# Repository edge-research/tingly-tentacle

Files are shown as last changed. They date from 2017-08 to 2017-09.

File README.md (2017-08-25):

# tingly-tentacle

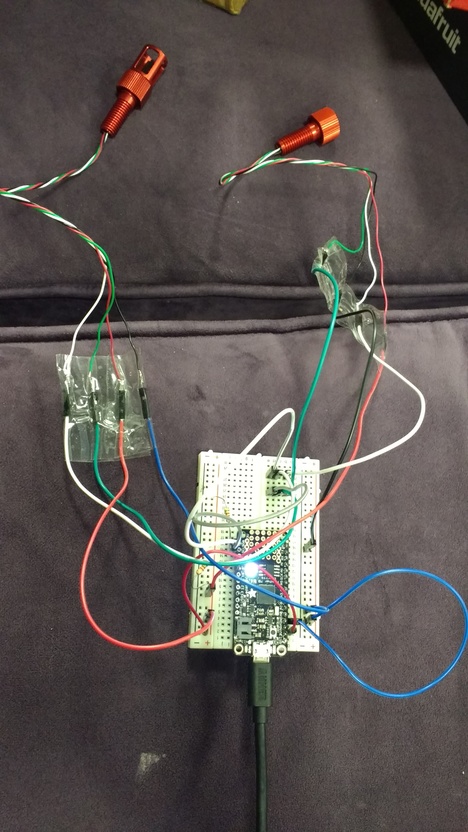
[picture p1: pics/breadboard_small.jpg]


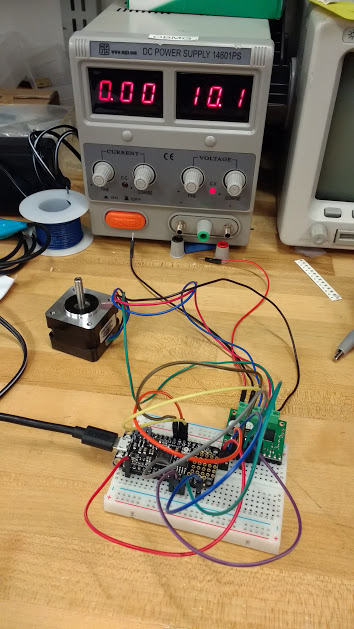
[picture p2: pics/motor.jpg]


# pololu stepper motor

- 1208 Stepper Motor: Bipolar, 200 Steps/Rev, 35×28mm, 10V, 0.5 A/Phase = 12.95
- https://www.pololu.com/product/1208

# pololu motor driver

- 2970 AMIS-30543 Stepper Motor Driver Carrier = 19.95
- https://www.pololu.com/product/2970
- http://www.onsemi.com/pub/Collateral/AMIS-30543-D.PDF
- https://github.com/pololu/amis-30543-arduino/

# blue robotics TSYS01

- https://github.com/bluerobotics/BlueRobotics_TSYS01_Library

# blue robotics MS5837

- http://docs.bluerobotics.com/bar30/
- https://github.com/bluerobotics/BlueRobotics_MS5837_Library

peristaltic pump system:
http://www.maschinenreich.com/wp-content/uploads/2017/03/XP88-Manual-A4-170320.pdf

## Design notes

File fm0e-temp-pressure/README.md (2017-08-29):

Datalogging temp and pressure (depth). 

# Adafruit Feather M0 Express

- [Adafruit Feather M0 Express Website](https://www.adafruit.com/product/3403) -- links and info.

# Blue Robotics TSYS01 'Fast Response' temp sensor

- [BR TSYS01 Website](https://www.bluerobotics.com/store/electronics/celsius-sensor-r1/) -- links and info.
- [BR TSYS01 Arduino Library](https://github.com/bluerobotics/BlueRobotics_TSYS01_Library)

# Blue Robotics MS5837 'Bar 30' pressure sensor

- [BR MS5837 Website](http://docs.bluerobotics.com/bar30/) -- links and info.
- [BR MS5837 Arduino Library](https://github.com/bluerobotics/BlueRobotics_MS5837_Library)

# Setup

- We're going to be programming the device using the Arduino IDE, but fetching the data off using CircuitPython. This allows us to utilize the on-board SPI Flash chip, which is lower-power and (likely) more reliable than an SD card.

- The Blue Robotics sensors should be connected to the Feather via i2c lines.  Follow the wiring diagrams on their respective web pages.  The SDA and SCL lines will each need a 10K 'pullup' -- i.e. they each need to be connected via a 10K resistor to VCC (3.3 V).

- Install the above Arduino libraries for the temp sensor and the pressure sensor in the 'libraries' folder for your Arduino installation.

- Set up your Arduino IDE to allow for interacting with Feather M0 Express boards as per instructions here.

### Initial programming of board for datalogging

- Double tap the 'reset' button to enter bootloader mode.
 
- Upload the 'feather_m0_express_br_temp_br_pressure_logger.ino' in this repo to the board.

- Once uploaded, double tap the 'reset' button again to enter bootloader mode.  Copy the '.UF2' file off the 'FEATHERBOOT' drive and store it.  This is your 'datalogger program', and will be needed after each time you collect data.
 
### Collecting the data after datalogging

- Double tap the 'reset' button to enter bootloader mode.

- Drag and drop the 'adafruit-circuitpython-feather_m0_express-2.0.0-beta.1.uf2' file onto the FEATHEROOT drive. 

- This will automatically reboot the board, and then mount as a 'CIRCUITPYTHON' drive. You can then drag-drop off the 'data.txt' file.

### Reprogramming the board to return to datalogging

- Double tap the 'reset' button to enter bootloader mode.

- Drag and drop your '.UF2' file (saved in step 1.) back onto the FEATHERBOOT drive.  This will automatically reboot the system and start running the Arduino datalogging program (may require a power cycle).

# Misc Notes

These sensors use 'D13' connectors for the i2c connection. Looks like matching connectors are avail on Digikey [here](https://www.digikey.com/product-detail/en/hirose-electric-co-ltd/DF13-4P-1.25DSA/H2193-ND/241767).

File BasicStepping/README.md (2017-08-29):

Uses the [AMIS-30543 Arduino library](https://github.com/edge-research/tingly-tentacle/tree/master/BasicStepping).  Code and wiring instructions [here](https://github.com/pololu/amis-30543-arduino).

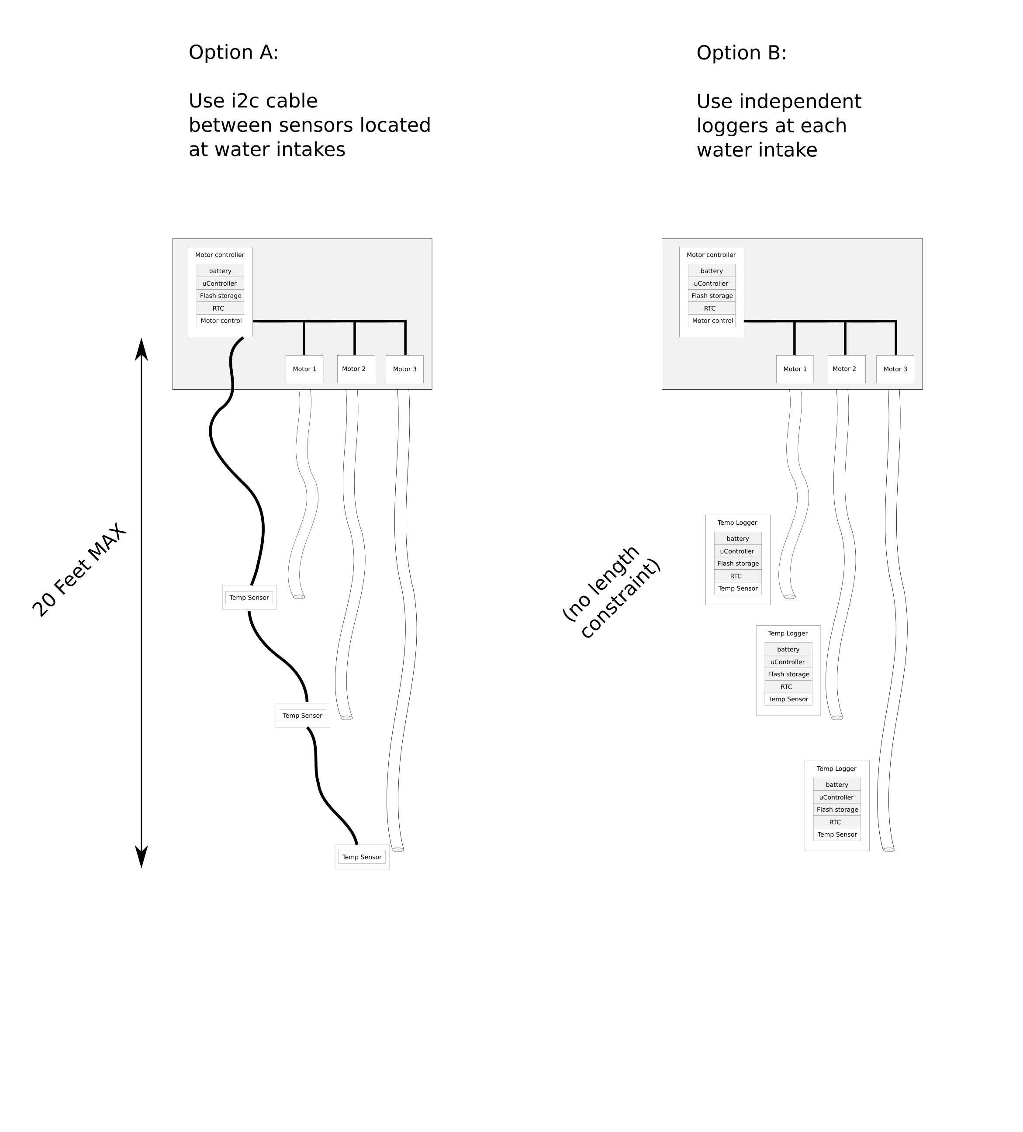
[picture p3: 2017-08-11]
docs/tt1.png

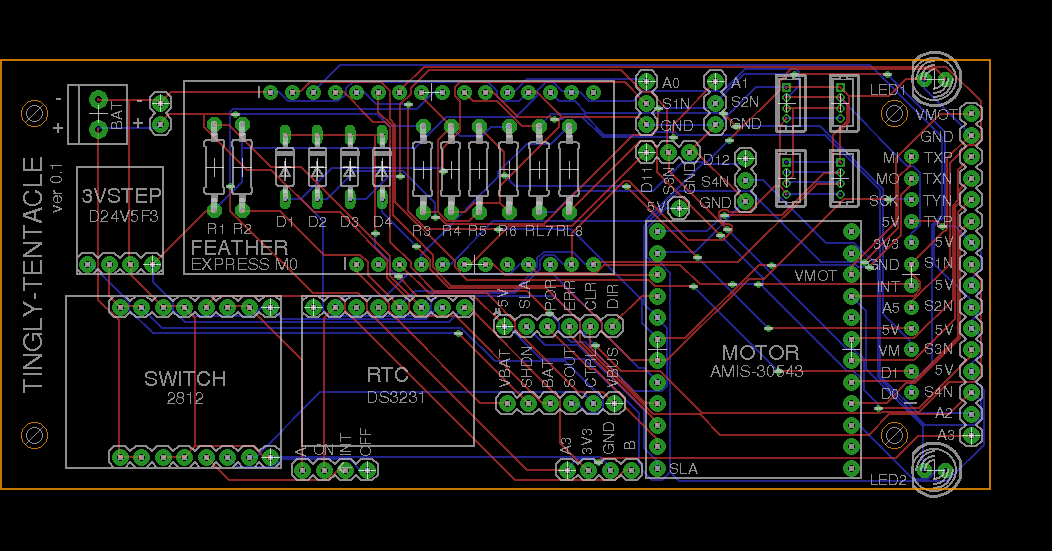
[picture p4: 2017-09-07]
mother_board/mother3.png

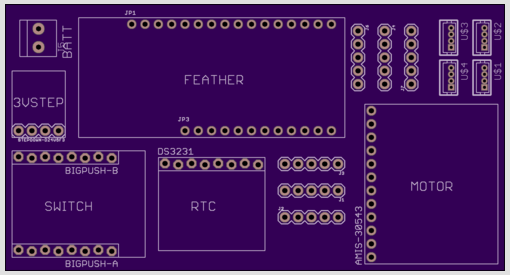
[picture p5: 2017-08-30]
mother_board/tingle-top.png

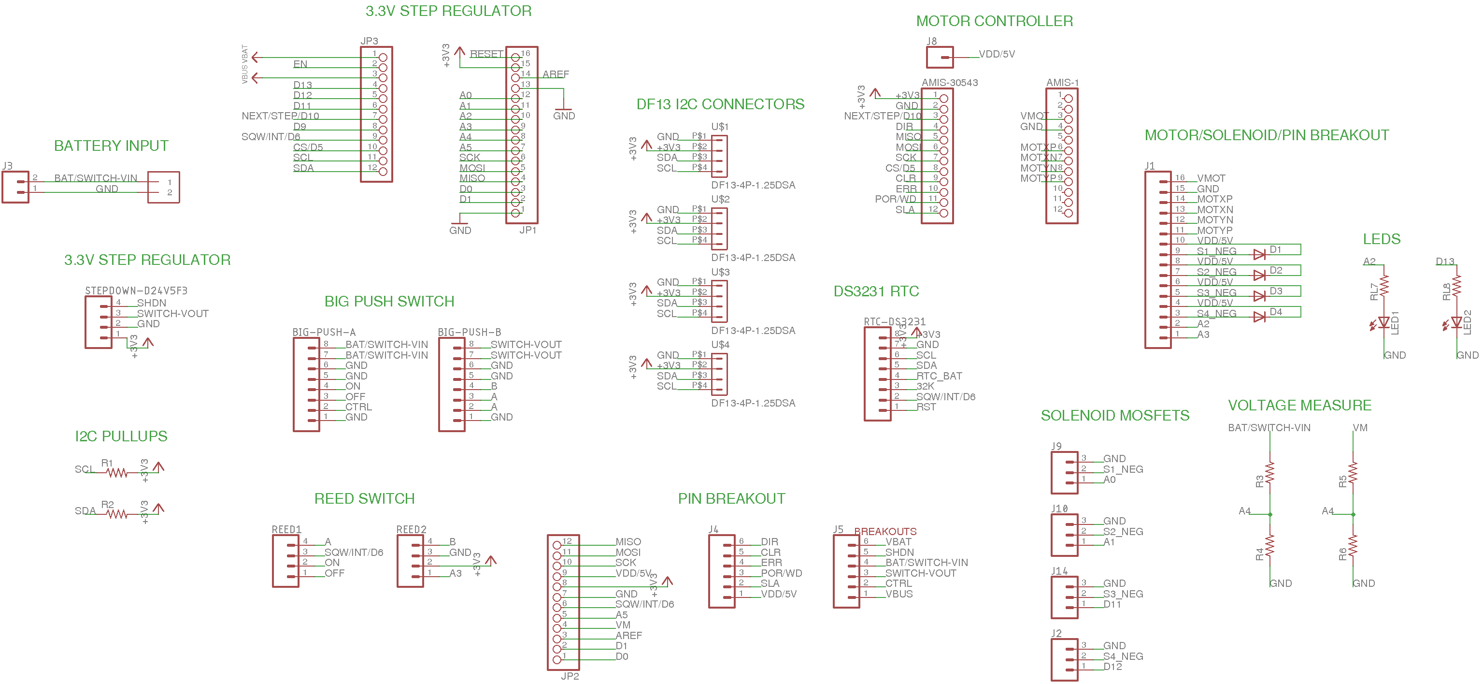
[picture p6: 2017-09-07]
mother_board/mother3_schem.png

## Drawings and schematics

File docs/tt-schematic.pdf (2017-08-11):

# Option A:

# Use i2c cable

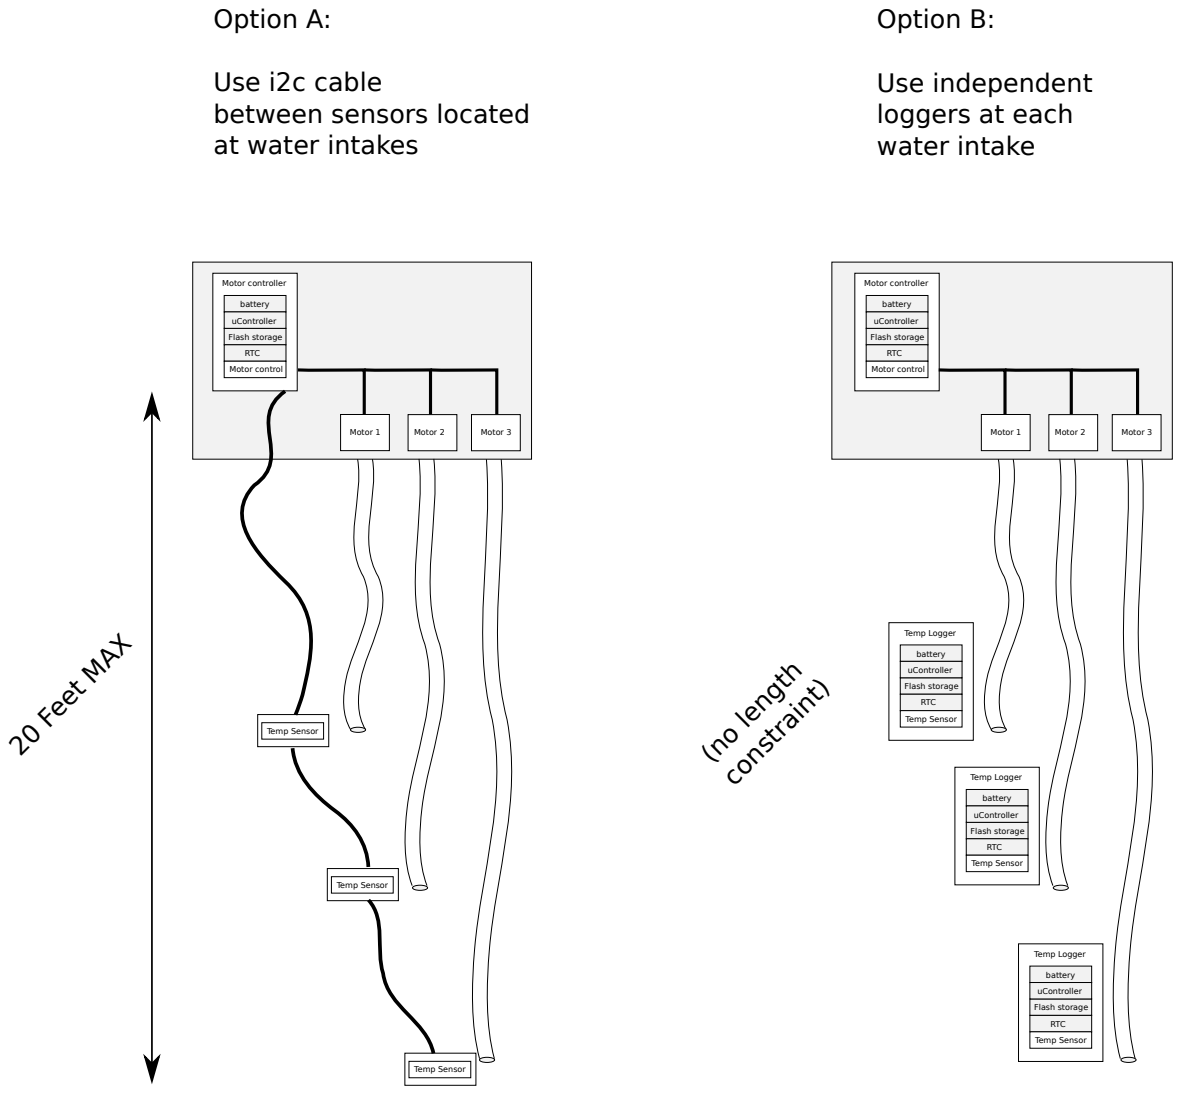
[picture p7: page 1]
RTC; battery; Flash storage; uController; Motor controller; Motor control; Motor 1; Motor 2; Motor 3; Temp Logger; Temp Sensor; 20 Feet MAX; (no length constraint); Option B:

Use independent
loggers at each
water intake

between sensors located
at water intakes

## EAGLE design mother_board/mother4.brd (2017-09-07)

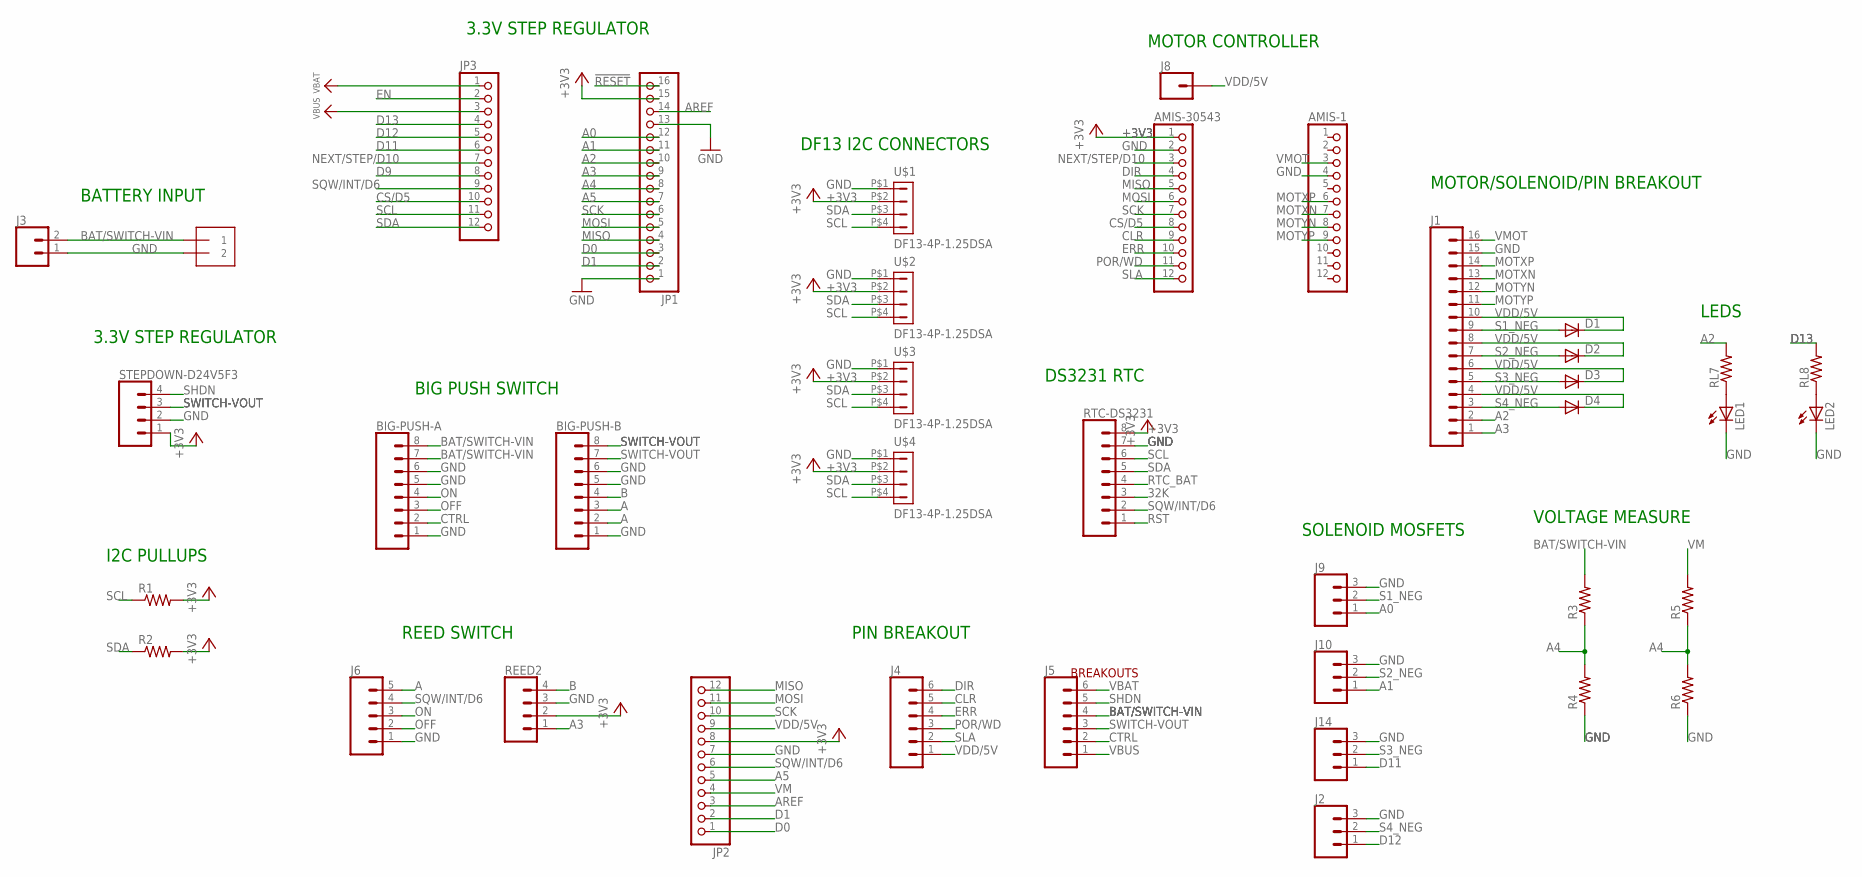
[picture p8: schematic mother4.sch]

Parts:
AMIS-1, AMIS-30543: PINHD-1X12-CB; 1X12-CB
BAT: 1X2-3.5MM
BIG-PUSH-A: CONN_08"; 1X08
BIG-PUSH-B: CONN_08"; 1X08
D1, D2, D3, D4: 1N4148DO35-7; DO35-7
J1: CONN_16; 1X16
J2, J9, J10, J14: CONN_03; 1X03
J3: CONN_02; 1X02
J4, J5: CONN_06SILK_FEMALE_PTH; 1X06
J6: CONN_05; 1X05
J8: CONN_01; 1X01
JP1: HEADER-1X16ROUND; 1X16_ROUND
JP2, JP3: HEADER-1X12; 1X12_ROUND
LED1, LED2: LED5MM
R1, R2, R3, R4, R5, R6: R-US_0207/10; 0207/10
REED2: CONN_04; 1X04
RL7, RL8: R-US_0207/10; 0207/10
RTC-DS3231: CONN_08"; 1X08
STEPDOWN-D24V5F3: CONN_04; 1X04
U$1, U$2, U$3, U$4: DF13-4P-1.25DSA

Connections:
32K: RTC-DS3231.3
!RESET: JP1.16
+3V3: AMIS-30543.1, JP1.15, JP2.8, R1.2, R2.2, REED2.2, RTC-DS3231.8, STEPDOWN-D24V5F3.1, U$1.P$2 (2), U$2.P$2 (2), U$3.P$2 (2), U$4.P$2 (2)
A: BIG-PUSH-B.2, BIG-PUSH-B.3, J6.5
A0: J9.1, JP1.12
A1: J10.1, JP1.11
A2: J1.2, JP1.10, RL7.2
A3: J1.1, JP1.9, REED2.1
A4: JP1.8, R3.1, R4.2, R5.1, R6.2
A5: JP1.7, JP2.5
AREF: JP1.14, JP2.3
B: BIG-PUSH-B.4, REED2.4
BAT/SWITCH-VIN: BAT.1, BIG-PUSH-A.7, BIG-PUSH-A.8, J3.2, J5.4, R3.2
CLR: AMIS-30543.9, J4.5
CS/D5: AMIS-30543.8, JP3.10
CTRL: BIG-PUSH-A.2, J5.2
D0: JP1.3, JP2.1
D1: JP1.2, JP2.2
D9: JP3.8
D11: J14.1, JP3.6
D12: J2.1, JP3.5
D13: JP3.4, RL8.2
DIR: AMIS-30543.4, J4.6
EN: JP3.2
ERR: AMIS-30543.10, J4.4
GND: AMIS-1.4, AMIS-30543.2, BAT.2, BIG-PUSH-A.1, BIG-PUSH-A.5, BIG-PUSH-A.6, BIG-PUSH-B.1, BIG-PUSH-B.5, BIG-PUSH-B.6, J1.15, J2.3, J3.1, J6.1, J9.3, J10.3, J14.3, JP1.1, JP1.13, JP2.7, LED1.K (C), LED2.K (C), R4.1, R6.1, REED2.3, RTC-DS3231.7, STEPDOWN-D24V5F3.2, U$1.P$1 (1), U$2.P$1 (1), U$3.P$1 (1), U$4.P$1 (1)
MISO: AMIS-30543.5, JP1.4, JP2.12
MOSI: AMIS-30543.6, JP1.5, JP2.11
MOTXN: AMIS-1.7, J1.13
MOTXP: AMIS-1.6, J1.14
MOTYN: AMIS-1.8, J1.12
MOTYP: AMIS-1.9, J1.11
unnamed: LED1.A, RL7.1
unnamed: LED2.A, RL8.1
NEXT/STEP/D10: AMIS-30543.3, JP3.7
OFF: BIG-PUSH-A.3, J6.2
ON: BIG-PUSH-A.4, J6.3
POR/WD: AMIS-30543.11, J4.3
RST: RTC-DS3231.1
RTC_BAT: RTC-DS3231.4
S1_NEG: D1.A, J1.9, J9.2
S2_NEG: D2.A, J1.7, J10.2
S3_NEG: D3.A, J1.5, J14.2
S4_NEG: D4.A, J1.3, J2.2
SCK: AMIS-30543.7, JP1.6, JP2.10
SCL: JP3.11, R1.1, RTC-DS3231.6, U$1.P$4 (4), U$2.P$4 (4), U$3.P$4 (4), U$4.P$4 (4)
SDA: JP3.12, R2.1, RTC-DS3231.5, U$1.P$3 (3), U$2.P$3 (3), U$3.P$3 (3), U$4.P$3 (3)
SHDN: J5.5, STEPDOWN-D24V5F3.4
SLA: AMIS-30543.12, J4.2
SQW/INT/D6: J6.4, JP2.6, JP3.9, RTC-DS3231.2
SWITCH-VOUT: BIG-PUSH-B.7, BIG-PUSH-B.8, J5.3, STEPDOWN-D24V5F3.3
VBAT: J5.6, JP3.1
VBUS: J5.1, JP3.3
VDD/5V: D1.C, D2.C, D3.C, D4.C, J1.4, J1.6, J1.8, J1.10, J4.1, J8.1, JP2.9
VM: JP2.4, R5.2
VMOT: AMIS-1.3, J1.16

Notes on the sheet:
BREAKOUTS
BATTERY INPUT
3.3V STEP REGULATOR
BIG PUSH SWITCH
REED SWITCH
PIN BREAKOUT
DS3231 RTC
SOLENOID MOSFETS
MOTOR/SOLENOID/PIN BREAKOUT
MOTOR CONTROLLER
I2C PULLUPS
DF13 I2C CONNECTORS
VOLTAGE MEASURE
LEDS

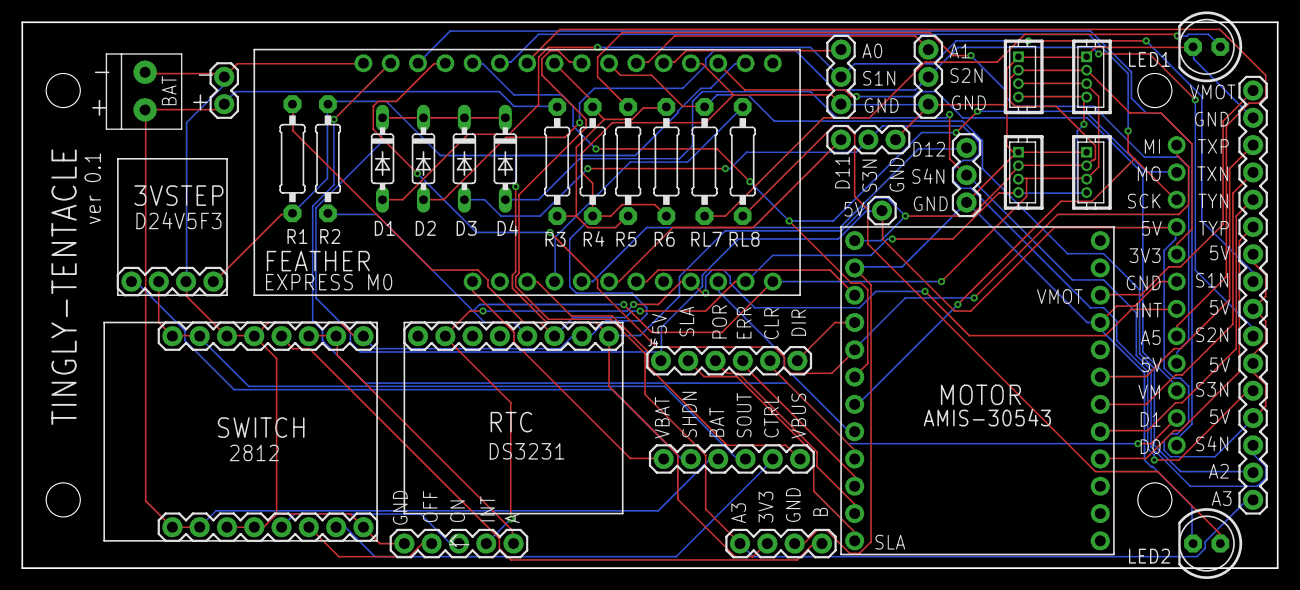
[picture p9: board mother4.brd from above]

Board: 2 copper layers, 116.8 x 50.8 mm, 39 parts (0 on the bottom side), 50 nets.

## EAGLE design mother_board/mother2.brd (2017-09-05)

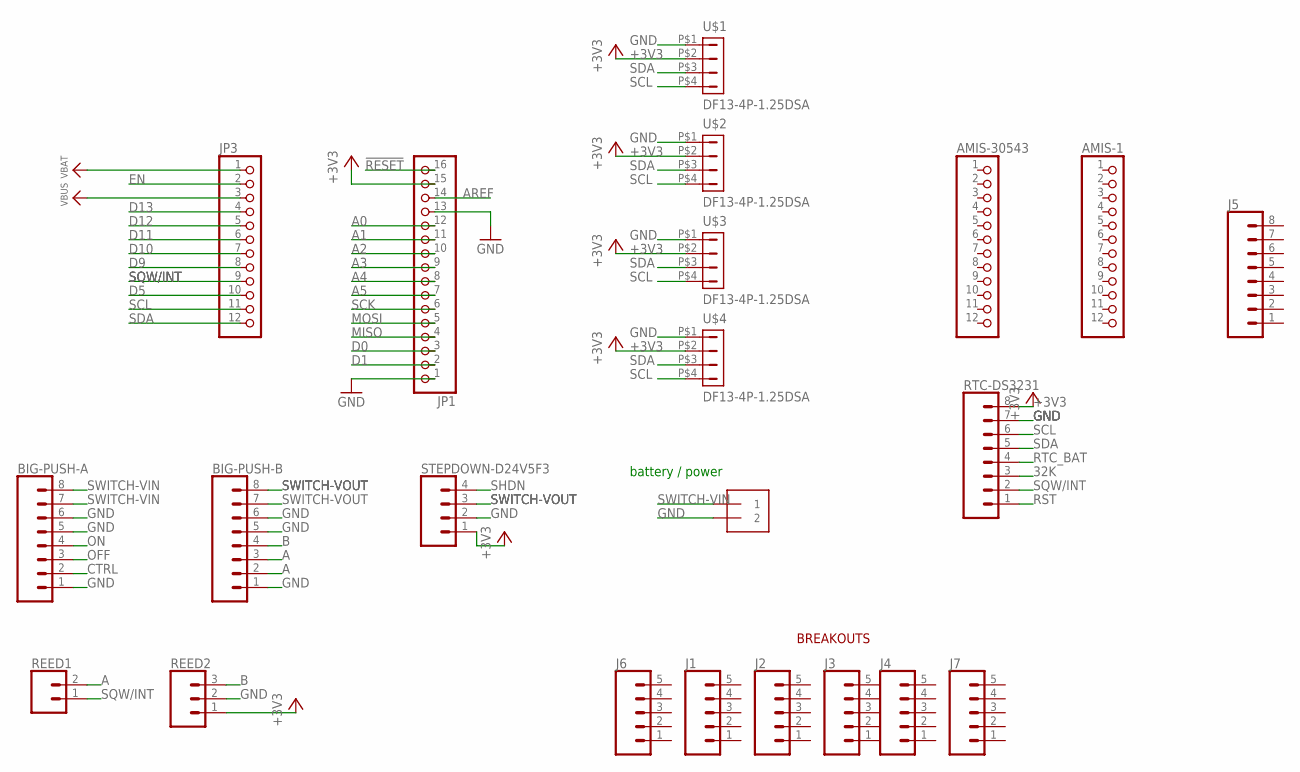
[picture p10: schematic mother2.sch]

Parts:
AMIS-1, AMIS-30543: PINHD-1X12-CB; 1X12-CB
BAT: 1X2-3.5MM
BIG-PUSH-A: CONN_08"; 1X08
BIG-PUSH-B: CONN_08"; 1X08
J1, J2, J3, J4, J6, J7: CONN_05; 1X05
J5: CONN_08"; 1X08
JP1: HEADER-1X16ROUND; 1X16_ROUND
JP3: HEADER-1X12; 1X12_ROUND
REED1: CONN_02; 1X02
REED2: CONN_03; 1X03
RTC-DS3231: CONN_08"; 1X08
STEPDOWN-D24V5F3: CONN_04; 1X04
U$1, U$2, U$3, U$4: DF13-4P-1.25DSA

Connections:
32K: RTC-DS3231.3
!RESET: JP1.16
+3V3: JP1.15, REED2.1, RTC-DS3231.8, STEPDOWN-D24V5F3.1, U$1.P$2 (2), U$2.P$2 (2), U$3.P$2 (2), U$4.P$2 (2)
A: BIG-PUSH-B.2, BIG-PUSH-B.3, REED1.2
A0: JP1.12
A1: JP1.11
A2: JP1.10
A3: JP1.9
A4: JP1.8
A5: JP1.7
AREF: JP1.14
B: BIG-PUSH-B.4, REED2.3
CTRL: BIG-PUSH-A.2
D0: JP1.3
D1: JP1.2
D5: JP3.10
D9: JP3.8
D10: JP3.7
D11: JP3.6
D12: JP3.5
D13: JP3.4
EN: JP3.2
GND: BAT.2, BIG-PUSH-A.1, BIG-PUSH-A.5, BIG-PUSH-A.6, BIG-PUSH-B.1, BIG-PUSH-B.5, BIG-PUSH-B.6, JP1.1, JP1.13, REED2.2, RTC-DS3231.7, STEPDOWN-D24V5F3.2, U$1.P$1 (1), U$2.P$1 (1), U$3.P$1 (1), U$4.P$1 (1)
MISO: JP1.4
MOSI: JP1.5
OFF: BIG-PUSH-A.3
ON: BIG-PUSH-A.4
RST: RTC-DS3231.1
RTC_BAT: RTC-DS3231.4
SCK: JP1.6
SCL: JP3.11, RTC-DS3231.6, U$1.P$4 (4), U$2.P$4 (4), U$3.P$4 (4), U$4.P$4 (4)
SDA: JP3.12, RTC-DS3231.5, U$1.P$3 (3), U$2.P$3 (3), U$3.P$3 (3), U$4.P$3 (3)
SHDN: STEPDOWN-D24V5F3.4
SQW/INT: JP3.9, REED1.1, RTC-DS3231.2
SWITCH-VIN: BAT.1, BIG-PUSH-A.7, BIG-PUSH-A.8
SWITCH-VOUT: BIG-PUSH-B.7, BIG-PUSH-B.8, STEPDOWN-D24V5F3.3
VBAT: JP3.1
VBUS: JP3.3

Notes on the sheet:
BREAKOUTS
battery / power

Board: 2 copper layers, 22 parts (0 on the bottom side), 9 nets, no tracks yet.

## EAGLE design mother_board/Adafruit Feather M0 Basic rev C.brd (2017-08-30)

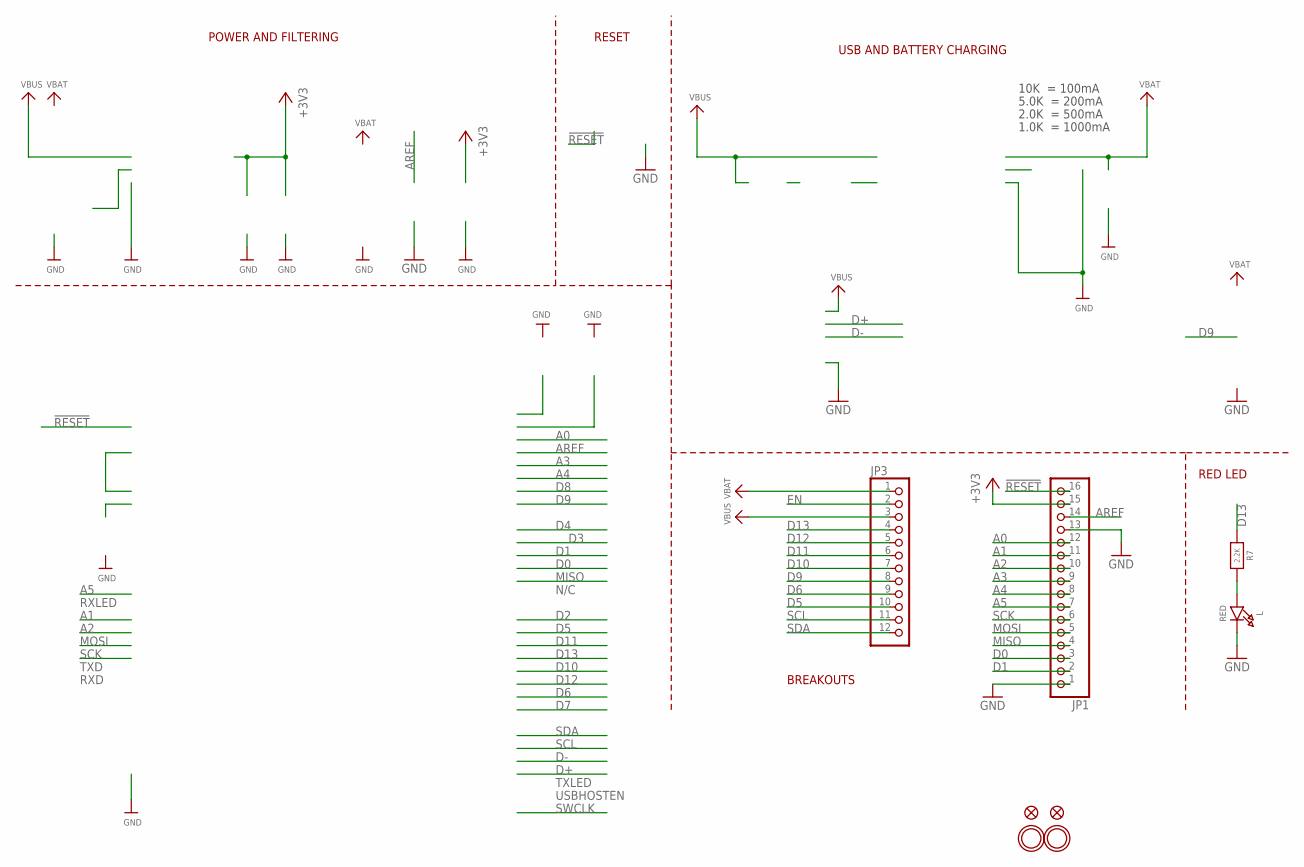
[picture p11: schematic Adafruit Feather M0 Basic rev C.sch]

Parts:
JP1: HEADER-1X16ROUND; 1X16_ROUND
JP3: HEADER-1X12; 1X12_ROUND
L: RED; CHIPLED_0805_NOOUTLINE
R7: 2.2K; 0603-NO
U$31, U$32: MOUNTINGHOLE2.5; MOUNTINGHOLE_2.5_PLATED
U$34, U$35: FIDUCIAL""; FIDUCIAL_1MM

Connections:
!RESET: JP1.16
+3V3: JP1.15
A0: JP1.12
A1: JP1.11
A2: JP1.10
A3: JP1.9
A4: JP1.8
A5: JP1.7
AREF: JP1.14
D0: JP1.3
D1: JP1.2
D5: JP3.10
D6: JP3.9
D9: JP3.8
D10: JP3.7
D11: JP3.6
D12: JP3.5
D13: JP3.4, R7.1
EN: JP3.2
GND: JP1.1, JP1.13, L.C
MISO: JP1.4
MOSI: JP1.5
unnamed: L.A, R7.2
SCK: JP1.6
SCL: JP3.11
SDA: JP3.12
VBAT: JP3.1
VBUS: JP3.3

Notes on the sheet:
POWER AND FILTERING
RESET
10K = 100mA
5.0K = 200mA
2.0K = 500mA
1.0K = 1000mA
N/C
TXLED
USBHOSTEN
RXLED
TXD
RXD
USB AND BATTERY CHARGING
BREAKOUTS
RED LED

Board: 2 copper layers, 12 parts (3 on the bottom side), 3 nets, no tracks yet.

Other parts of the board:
U$7, U$12: ADAFRUIT_3.5MM
U$9: FEATHERLOGO
U$13: PCBFEAT-REV-040

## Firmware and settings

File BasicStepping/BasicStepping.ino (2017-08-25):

/* This example shows basic use of the AMIS-30543 stepper motor
driver.

It shows how to initialize the driver, set the current limit, set
the micro-stepping mode, and enable the driver.  It shows how to
send pulses to the NXT/STEP pin to get the driver to take steps
and how to switch directions using the DIR pin.  The DO pin is
not used and does not need to be connected.

Before using this example, be sure to change the
setCurrentMilliamps line to have an appropriate current limit for
your system.  Also, see this library's documentation for
information about how to connect the driver:

    http://pololu.github.io/amis-30543-arduino/
*/

#include <SPI.h>
#include <AMIS30543.h>

const uint8_t amisDirPin = 12;
const uint8_t amisStepPin = 11;
const uint8_t amisSlaveSelect = 10;

AMIS30543 stepper;

void setup()
{

  pinMode(LED_BUILTIN, OUTPUT);


for (int i=0; i<5;i++) {
  digitalWrite(LED_BUILTIN, HIGH);   // turn the LED on (HIGH is the voltage level)
  delay(1000);                       // wait for a second
  digitalWrite(LED_BUILTIN, LOW);    // turn the LED off by making the voltage LOW
  delay(1000);  

}
  
  SPI.begin();
  stepper.init(amisSlaveSelect);

  // Drive the NXT/STEP and DIR pins low initially.
  digitalWrite(amisStepPin, LOW);
  pinMode(amisStepPin, OUTPUT);
  digitalWrite(amisDirPin, LOW);
  pinMode(amisDirPin, OUTPUT);

  // Give the driver some time to power up.
  delay(1);

  // Reset the driver to its default settings.
  stepper.resetSettings();

  // Set the current limit.  You should change the number here to
  // an appropriate value for your particular system.
  stepper.setCurrentMilliamps(132);

  // Set the number of microsteps that correspond to one full step.
  stepper.setStepMode(32);

  // Enable the motor outputs.
  stepper.enableDriver();

  digitalWrite(LED_BUILTIN, HIGH);   // turn the LED on (HIGH is the voltage level)
  delay(200);                       // wait for a second
  digitalWrite(LED_BUILTIN, LOW);    // turn the LED off by making the voltage LOW
  delay(200);  
  
}

void loop()
{

  digitalWrite(LED_BUILTIN, HIGH);   // turn the LED on (HIGH is the voltage level)
  delay(1000);                       // wait for a second
  digitalWrite(LED_BUILTIN, LOW);    // turn the LED off by making the voltage LOW
  delay(1000);  
  
  // Step in the default direction 1000 times.
  setDirection(0);
  for (unsigned int x = 0; x < 1000; x++)
  {
    step();
  }

  // Wait for 300 ms.
  delay(300);

  // Step in the other direction 1000 times.
  setDirection(1);
  for (unsigned int x = 0; x < 1000; x++)
  {
    step();
  }

  // Wait for 300 ms.
  delay(300);
}

// Sends a pulse on the NXT/STEP pin to tell the driver to take
// one step, and also delays to control the speed of the motor.
void step()
{
  // The NXT/STEP minimum high pulse width is 2 microseconds.
  digitalWrite(amisStepPin, HIGH);
  delayMicroseconds(3);
  digitalWrite(amisStepPin, LOW);
  delayMicroseconds(3);

  // The delay here controls the stepper motor's speed.  You can
  // increase the delay to make the stepper motor go slower.  If
  // you decrease the delay, the stepper motor will go fast, but
  // there is a limit to how fast it can go before it starts
  // missing steps.
  delayMicroseconds(2000);
}

// Writes a high or low value to the direction pin to specify
// what direction to turn the motor.
void setDirection(bool dir)
{
  // The NXT/STEP pin must not change for at least 0.5
  // microseconds before and after changing the DIR pin.
  delayMicroseconds(1);
  digitalWrite(amisDirPin, dir);
  delayMicroseconds(1);
}

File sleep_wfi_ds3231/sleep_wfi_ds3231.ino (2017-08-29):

//Interrupts for Battery management/saving using MCU power down mode. /INT from DS3231 is connected to 'interrupt_pin' of MCU, and also needs a 10K pullup to VDD.

#include <Wire.h>
#include "DS3231.h"

#define interruptPin 6

DS3231 rtc; //Create the DS3231 object

const int interval_sec = 5; //interval in seconds
const int sleep_depth = 0; // Enable Idle0 mode - sleep CPU clock only
//const int sleep_depth = 1; // Idle1 - sleep CPU and AHB clocks
//const int sleep_depth=2; // Idle2 - sleep CPU, AHB, and APB clocks

void setup () 
{

  
	 Serial.begin(9600);
   Serial.println('beginning ...');
	 Wire.begin();
	
	 rtc.begin(); 
   
}


void loop () 
{

	for (int i=0;i<3;i++) { // indicate visually
    Blink(LED_BUILTIN,1000);
   }
   
   fall_asleep(interval_sec,sleep_depth);

   for (int i=0;i<3;i++) { // indicate visually
    Blink(LED_BUILTIN,100);
   }
   delay(1000);
   Serial.println(" External Interrupt detected "); //indicate on serial port

} 

  
//Interrupt service routine for external interrupt
void EIC_ISR()
{
  //Keep this as short as possible. Possibly avoid using function calls
  detachInterrupt(digitalPinToInterrupt(interruptPin));
  
}

void Blink(byte PIN, int DELAY_MS) {
  //Blink an LED
  pinMode(PIN, OUTPUT);
  digitalWrite(PIN, HIGH);
  delay(DELAY_MS);
  digitalWrite(PIN, LOW);
  delay(DELAY_MS);
}


void fall_asleep (int interval_sec, int sleep_depth) {

  rtc.clearAlarm(); //resets the alarm interrupt status on the RTC
  attachInterrupt(digitalPinToInterrupt(interruptPin), EIC_ISR, FALLING);  // Attach interrupt to pin interrupt_pin with an ISR
 
  SYSCTRL->XOSC32K.reg |=  (SYSCTRL_XOSC32K_RUNSTDBY | SYSCTRL_XOSC32K_ONDEMAND); // set external 32k oscillator to run when idle or sleep mode is chosen
  REG_GCLK_CLKCTRL  |= GCLK_CLKCTRL_ID(GCM_EIC) |  // generic clock multiplexer id for the external interrupt controller
                       GCLK_CLKCTRL_GEN_GCLK1 |  // generic clock 1 which is xosc32k
                       GCLK_CLKCTRL_CLKEN;       // enable it
  while (GCLK->STATUS.bit.SYNCBUSY);              // write protected, wait for sync

  EIC->WAKEUP.reg |= EIC_WAKEUP_WAKEUPEN4;        // Set External Interrupt Controller to use channel 4 (interrupt_pin)


  if (sleep_depth==0) PM->SLEEP.reg |= PM_SLEEP_IDLE_CPU;  // Enable Idle0 mode - sleep CPU clock only
  if (sleep_depth==1) PM->SLEEP.reg |= PM_SLEEP_IDLE_AHB; // Idle1 - sleep CPU and AHB clocks
  if (sleep_depth==2) PM->SLEEP.reg |= PM_SLEEP_IDLE_APB; // Idle2 - sleep CPU, AHB, and APB clocks

  // It is either Idle mode or Standby mode, not both. 
  SCB->SCR |= SCB_SCR_SLEEPDEEP_Msk;   // Enable Standby or "deep sleep" mode
  
  
  DateTime now = rtc.now(); //get the current time
  DateTime nextAlarm = DateTime(now.unixtime() + interval_sec);
  rtc.enableAlarm(nextAlarm); //Sets the alarm on the RTC to the specified time (using the DateTime Object passed in)
  delay(10); //wait for a moment for everything to complete
  __WFI();
}

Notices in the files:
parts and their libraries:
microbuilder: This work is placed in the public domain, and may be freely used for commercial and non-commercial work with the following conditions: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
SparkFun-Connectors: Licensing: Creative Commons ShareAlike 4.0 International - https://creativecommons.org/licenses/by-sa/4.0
